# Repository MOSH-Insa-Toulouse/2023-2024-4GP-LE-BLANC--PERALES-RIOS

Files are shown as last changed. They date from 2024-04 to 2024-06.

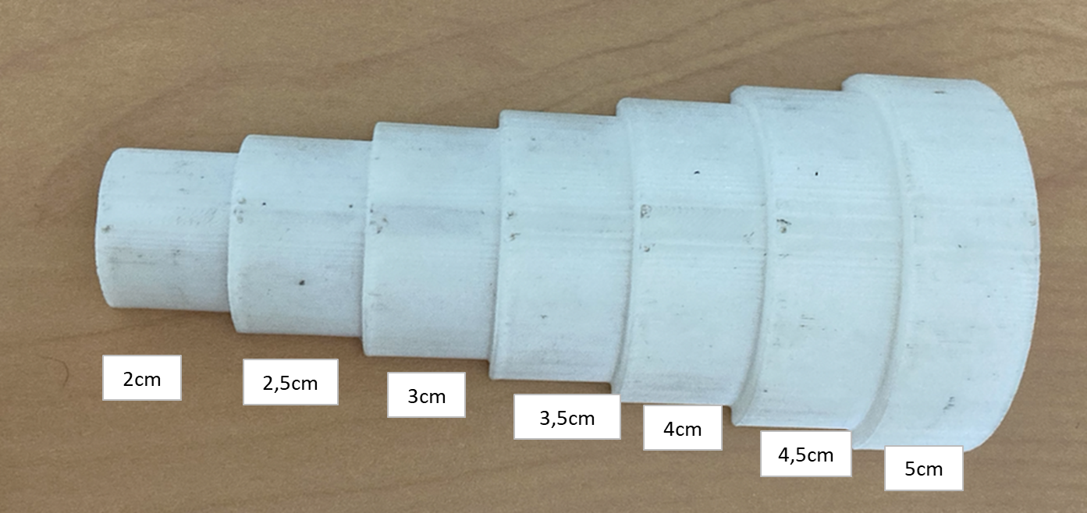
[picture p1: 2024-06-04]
Images/Bench_test.png

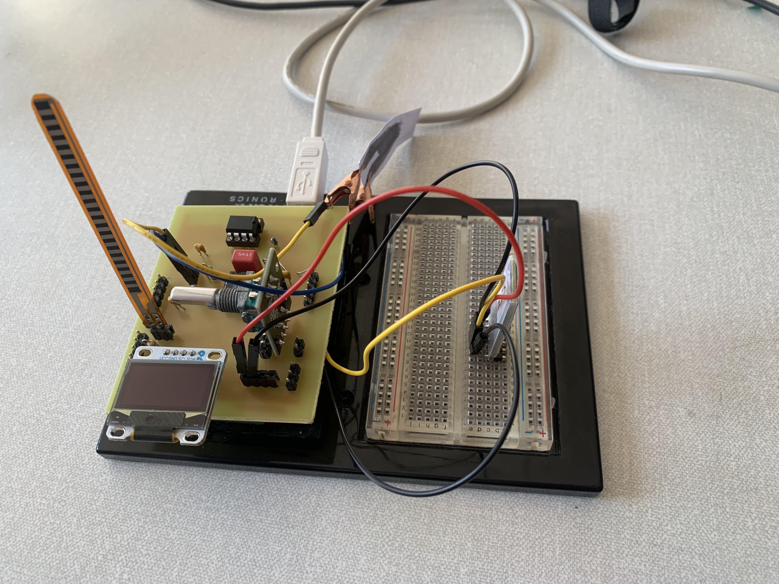
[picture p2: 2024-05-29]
Images/Complete_PCB.jpg

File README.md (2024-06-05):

# Graphite-based sensor project

## Students: Maël LE BLANC, Daniel PERALES RIOS

Département de Génie Physique

Institut National des Sciences Appliquées de Toulouse

# Introduction
The aim of this project is to study a graphite-based low-tech sensor, based on the publication "Pencil Drawn Strain Gauges and Chemiresistors on Paper" by Cheng-Wei Lin, Zhibo Zhao, Jaemyung Kim & Jiaxing Huang, published on Nature in 2014.

According to this research, graphite particles, deposited by coloring a sensor trace, can act as strain gauges. These strain gauges can then be used to measure resistances of the order of the Giga-ohm (10E9 Ohms), for a much cheaper price than buying a multimeter able to measure this order of resistance.

To study this graphene-based low-tech sensor, we have made an amplifier circuit that allows to measure the current flowing through the graphite sensor. This current is very small, and to measure it we would need a very expensive multimeter. Moreover, as the resistance of the graphene sensor depends on each graphite sensor, we have added a digital potentiometer in one of the resistances of the amplifier circuit. This allows for tuning the circuit to each sensor. We have also added a flex sensor to the project. The resistance of this sensor depends on the bending angle applied to it.

All the sensors and measurements are managed through an Arduino UNO board. In this Arduino UNO board, we have also connected an OLED screen that displays the data being measured. We have also implemented a simple menu in the screen that can be controlled through a rotary encoder. All the gathered data is then sent via a Bluetooth® module to an Android device though an app we have built using MIT’s App Inventor.

Finally, we have mounted all the sensors in a PCB we have built from scratch using KiCAD v7.0.

This project covers the entire sensor field, right up to the development of a datasheet and test bench for this sensor.

- [Deliverables](#deliverables)

- [Physics behind the resistance change in the graphite and the flex sensors](#physics-behind-the-resistance-change-in-the-graphite-and-the-flex-sensors)

- [Necessary components and image of the finished project](#necessary-components-and-image-of-the-finished-project)

- [Arduino code](#arduino-code)
  
    - [Potentiometer menu](#potentiometer-menu)
    - [Flex sensor menu](#flex-sensor-menu)
    - [Graphite sensor menu](#graphite-sensor-menu)

- [KiCAD PCB design](#kicad-pcb-design)

    - [Amplifier circuit](#amplifier-circuit)
    - [LTC1050 Operationnal amplifier](#ltc1050-operationnal-amplifier)
    - [MCP41050 Digital potentiometer](#mcp41050-digital-potentiometer)
    - [Graphite sensor](#graphite-sensor)
    - [Flex sensor](#flex-sensor)
    - [KY-040 Rotary encoder](#ky-040-rotary-encoder)
    - [OLED screen](#oled-screen)

- [Android App](#android-app)

- [Test Bench](#test-bench)

# Deliverables

- Arduino shield containing the BT module, the OLED screen...
- Arduino code for controlling the Arduino shield.
- Android app that is able to gather the data sent by the Arduino shield.
- Datasheet describing the results of some measurements for the sensors. 

To write the datasheet, a bench test must be used or built. In our project, we have used a bench test that was already at the department, and that was perfect for our case.

# Physics behind the resistance change in the graphite and the flex sensors

For the graphite and the flex sensors, let’s imagine they were a 2D layer of atoms to which we could apply tension and compression. This 2D layer of atoms would have a mean distance per atom depending on the atomic arrangement. The greater these mean distance between atoms is, the more difficult it is for an electron to “jump” from one atom to another, and vice versa. When these electron “jumps” are coordinated following the same direction (for example when we apply a potential difference between the two extremes of the 2D plane), we can say that an electric current is present. When this happens, it is called "percolation".

On the one hand, when a compression force is applied to that 2D layer of atoms, the atoms would get closer to each other, thus reducing the mean distance per atom, facilitating the flow of an electric current, and reducing then the resistance. 

On the other hand, when a tensile force is applied to the 2D layer of atoms, the atoms would get farther apart from each other, thus increasing the mean distance per atom, making the electron “jumps” less favorable, and increasing the resistance. 

We can see in figure 1 how the compressive and tensile forces affect the geometry of the 2D plane. When generalizing the 2D plane to a 3D thin surface, the principle of the measurement stays the same.

Imagen1

Figure 1: Principle of the resistance measurement for the graphite and flex sensors. Extracted from “Pencil Drawn Strain Gauges and Chemiresistors on Paper”, by Cheng-Wei et al.

# Necessary components and image of the finished project

In figure 2, the finished project, with all the components mounted on the shield, is showed. The only component that not mounted in the shield has been the Bluetooth module, since what we thought to be a connection error was blocking the Arduino code from running.

To carry out this project, we needed: 
  - 1 graphite-based paper sensor
  - 1 flex sensor
  - 1 LTC1050 operational amplifier
  - 1 MCP41050 digital potentiometer
  - 1 KY-040 rotary encoder
  - 1 Arduino UNO
  - 1 OLED screen
  - 1 HC-05 Bluetooth® module
  - Resistances
  - Capacitors

PCB_complet

Figure 2: Image of the complete project. The Bluetooth module is mounted on a separate Arduino breadboard, but this does not have any impact on the functioning of the program.

# Arduino code

The logic behind the Arduino program can be found in the logic chart in figure 3.

bP9DRXin34RtEWMHLN85UvFunudH6WtgvW2CXl2ebIX1efAwHUzUIPunCi1iiZ3WaSZtFWgyJu9HihDAZ5Y2v-X_ae3689IZKkrQgSMH98UbMkpPY45h_X1exu9dOac0t44md4h1WmZg7eYrxoY2OQ4OSv1fxxUlsqthIXJBKMMvp4QZ6CzBfTvxOmbk7He-4ESxC0bkpvJk5C1YOr (1)

Figure 3: Logic chart for the Arduino code, that shows what are the main procedures and methods and what the code mainly does.

The is a main menu with three options, and the user can choose between each of these three options: the potentiometer, the flex sensor and the graphite sensor. These menus are showed below.

## Potentiometer menu

In this menu, the user selects the resistance value to be given to the potentiometer by placing the cursor over the available values. The user exits the calibration menu by pressing the encoder button. 



Figure 4: Potentiometer menu.

## Flex sensor menu

In this menu, the value of the resistance and the value of the angle of the flex sensor are displayed.  



Figure 5: Flex sensor menu.

## Grpahite sensor menu

In this menu, the user can see the current value of the graphite sensor. The user exits to the main menu by pressing the encoder button.



Figure 6: Graphite sensor menu.

# KiCAD PCB design

To realise our PCB, we have used KiCAD under its 7.0 version.

First of all, we had to reproduce the electrical amplifier circuit (resistances, capacitors...) with a few changes and component additions. In order to adjust the gain of our circuit, we have replaced the resistance R2 by an MCP41050 digital potentiometer which can be controlled using the KY-040 rotary encoder. Then, for the realisation of the test bench, we had to add some components that need to be connected to the power source, such as the flex sensor, the Bluetooth® module or the OLED screen. For that, we have created some symbols associated to the new elements. 

On figure 7, it is possible to see our complete electrical circuit realised in KiCAD with the different symbols of the components. 

Sin título (1)

Figure 7 : Complete schematic of the electrical circuit in KiCAD for the project.

Then, the second part is to realise the footprint of the PCB on KiCAD. However, all the components and the whole circuit have to fit on Arduino Uno Shield. So, the spatial arrangement must be thoughtful, while considering the 3D shape of the components and the specifications we have to follow for the PCB printing. 

For the most commons components, we've used some predefined footprints but for the others we've created some specifical footprints thanks to the software. All the footprints can be found in the KiCAD folder.

## Amplifier circuit

The main role of the amplifier is to amplify sensor output voltages to make them measurable.

On figure 8 can be seen the electrical circuit of the amplifier.



Figure 8: Schematic of the operationnal amplifier circuit in KiCAD.

## LTC1050 Operationnal amplifier

The LTC1050 is the operationnal amplifier used in our amplifier circuit that can be observed in figure 9.

DIP-8

Figure 9: LTC1050 operational amplifier.

## MCP41050 Digital potentiometer

The MCP41050 is the digital potentiometer used in our project. It varies up to 50,000 ohms depending on the command sent.
It has eight connections pins as can be seen in figure 10. 

Microchip-MCP41050-I_SN-image

Figure 10: MCP41050 digital potentiometer.

## Graphite sensor

The graphite sensor used in our project is made from paper with a trace to be colored in with different pencils. 
In our electrical circuit, the sensor is connected between the 5V (Vcc) source and the positive input of the amplifier (Vout), as can be seen in figure 11.

Graphite_sensor

Figure 11: Schematic for the graphite sensor. Extracted from Niels Brun and Paul Besnard's GitHub site.

## Flex sensor

The flex sensor, used for comparing the graphite-sensor measures, is mounted in a voltage divider bridge. 

Flex_sensor

Figure 12: Flex sensor. 

## KY-040 Rotary encoder

The rotary encoder is a main part of our project. It allows the user to change the selected menu, enter and exit menus by turning or pressing the encoder.
The rotary encoder has five pins connected to differents parts of the shield, as you can see on figure 13.  

Encodeur_rotatoire

Figure 13: Rotary encoder KY-040.

## OLED screen

On the Arduino shield, the OLED screen is connected to four pins, as you can see on figure 14.

OLED_screen

Figure 14: The OLED screen, with four pins.

# Android app

The Android app has been coded using MIT's app inventor. In figure 15 can be seen a logic chart for the functioning of the app.

Android_app_logic_chart

Figure 15: Logic chart for the Android app.

In figure 16 can be seen the code blocks for the Android app. 

Code_blocks_app (1)

Code_blocks_app (2)

Figure 16: Code blocks for the Android app. 

Moreover, we have coded an improved version of the program with a login function, whose code appears in figure 17.

Code_blocks_app_with_login (1)

Code_blocks_app_with_login (2)

Figure 17: Code blocks for the Android app with the login function.

Next, in figures 18 and 19 are presented the data capture screen and the login screen, respectively.

App_screen

Figure 18: Data capture screen.

App_screen_with_login

Figure 19: Login screen.

# Test bench

The last part of our project was to realize the test bench to acquire the data from our sensors. 

To realize the measures, we have decided to use a test bench consisting of semi-cylinders going from 2 to 5 cm in diameter, with steps of 0.5 cm in between each semi-cylinder, as you can see on figure 20.

Bench_test

Figure 20: Test bench used.

We have tested 5 graphite-sensors. Each, made with a different type of pencil: 3B, 2B, B, H, 2H. 
To carry out the measurements, we placed the sensors on the various cylinders, in tension and compression, as can be seen respectively in figures 21 and 22. This enabled us to measure differences in resistance as a function of pencil type and deformation. 

Deformation_tension

Figure 21: Deformation in tension.

Deformation_compression

Figure 22: Deformation in compression.

In figure 23 the results for the flex sensor in tension are showed. 

Deformation_tension_flex

Figure 23: Results for the flex sensor, in tension.

The complete results are described and presented in the graphite sensors' datasheet, available in the Datasheet folder.

With our results it is found that the softer the pencil is (in our case, 3B is the softer pencil), the less sensitive it is. This is the same conclusion, saving the distance, of Wei et al. in “Pencil Drawn Strain Gauges and Chemiresistors on Paper”.

For any question concerning our sensor project, please contact: perales@insa-toulouse.fr / m_leblan@insa-toulouse.fr

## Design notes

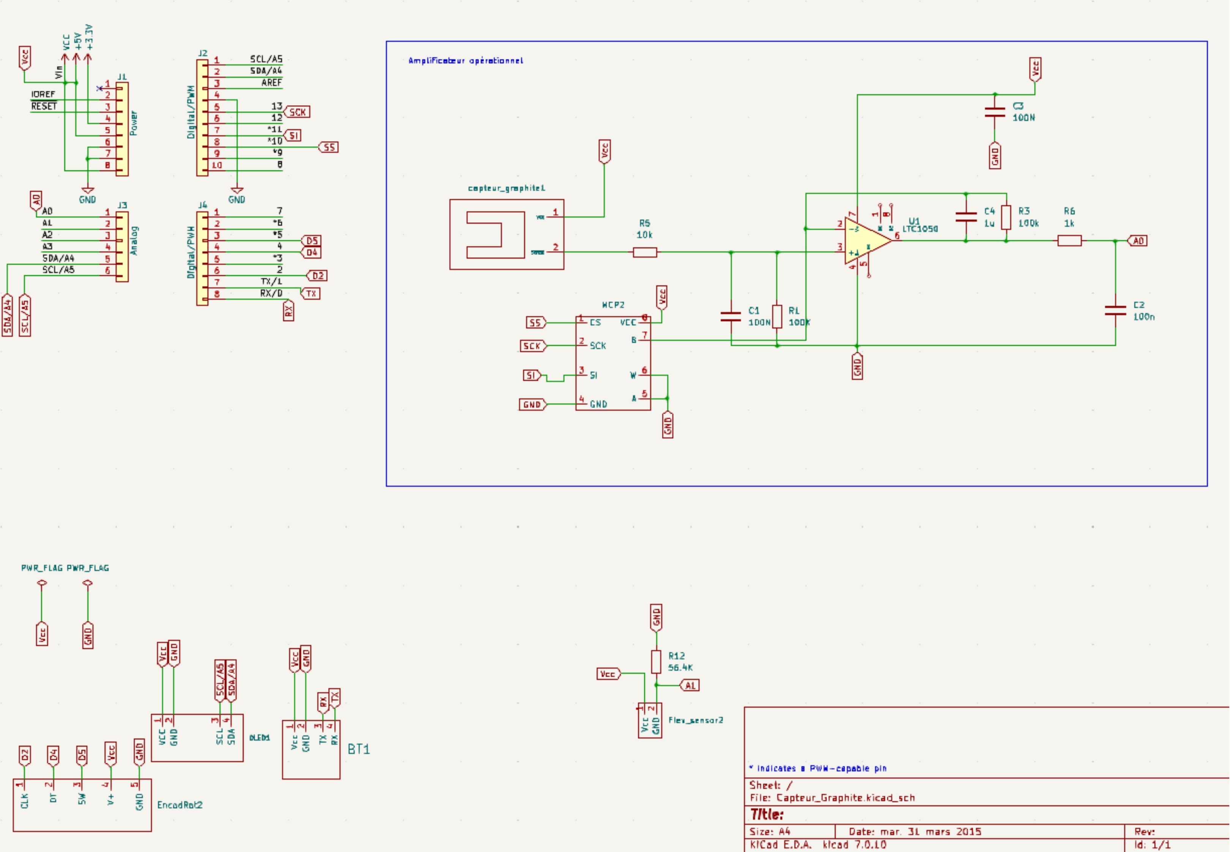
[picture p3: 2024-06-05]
KiCAD_PCB/Complete_schematic_analog.png

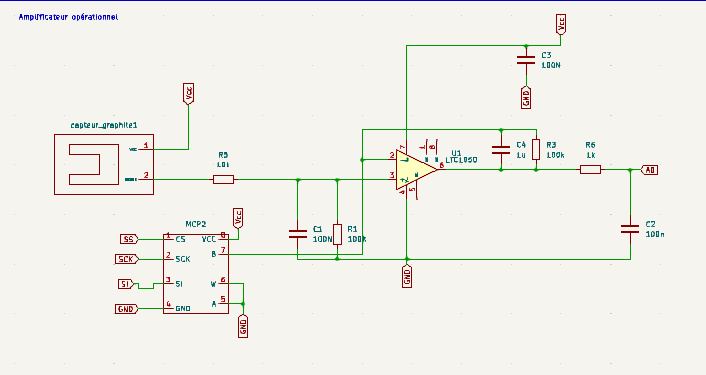
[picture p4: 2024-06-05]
KiCAD_PCB/Amplifier_schematic_analog.png

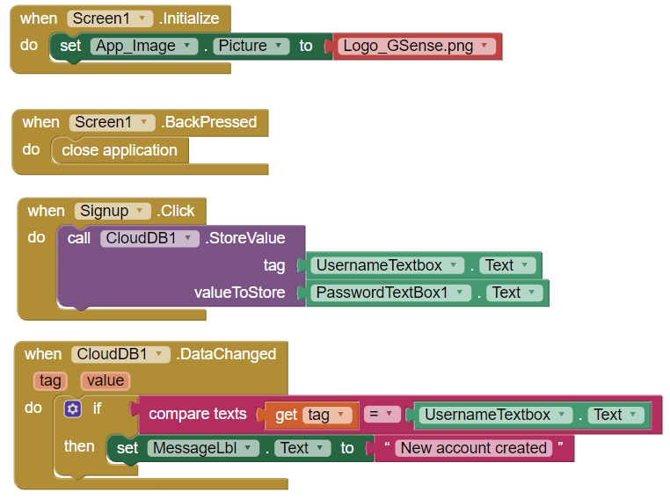
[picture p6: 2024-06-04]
Images/Code_blocks_app_with_login (1).png

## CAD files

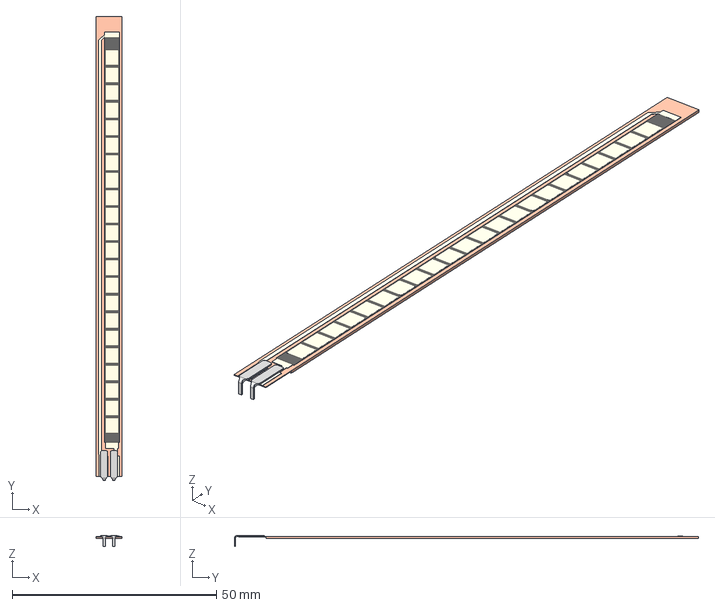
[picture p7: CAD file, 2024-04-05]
KiCAD_PCB/3D_models/flex_sensor/FS-L-0095-103-ST - Assembly.stp
6.45 x 113.5 x 2.77 mm
FS-L-0095-103-ST - Base
FS-L-0095-103-ST - Top

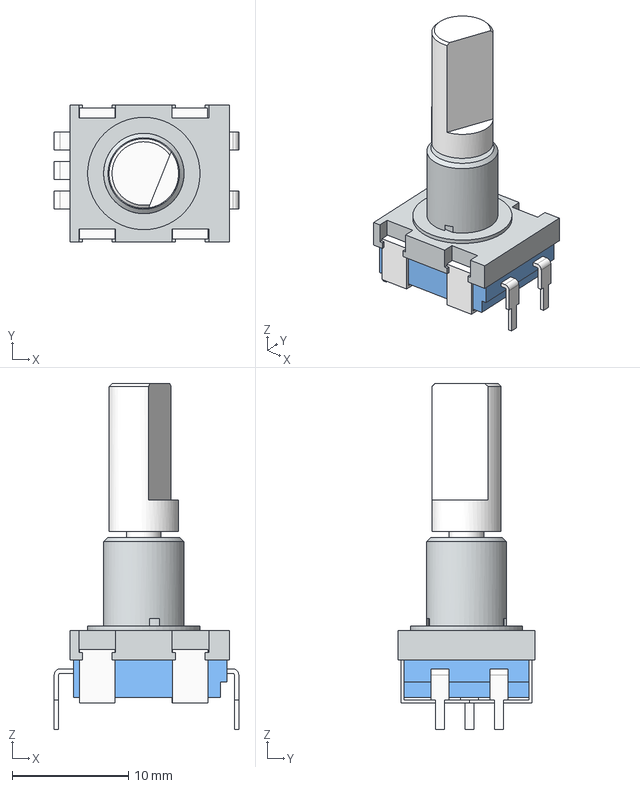
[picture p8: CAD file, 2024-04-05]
KiCAD_PCB/3D_models/rotary encoder step files/Step Files/Rotary Encoder without pcb Assembly.stp
15.8 x 11.8 x 29.7 mm
mtg flange
body_encoder
pins_encoder body_2 x 5
shaft_encoder

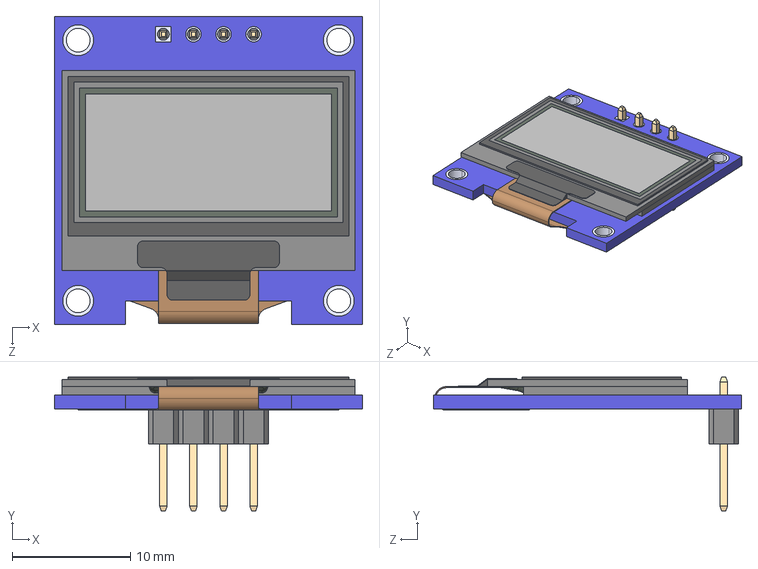
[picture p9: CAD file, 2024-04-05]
KiCAD_PCB/3D_models/DM-OLED096-636--3DModel-STEP-56544.STEP
26.0 x 11.3 x 26.0 mm
DM-OLED096-636_Module
DM-OLED096-636_Panel

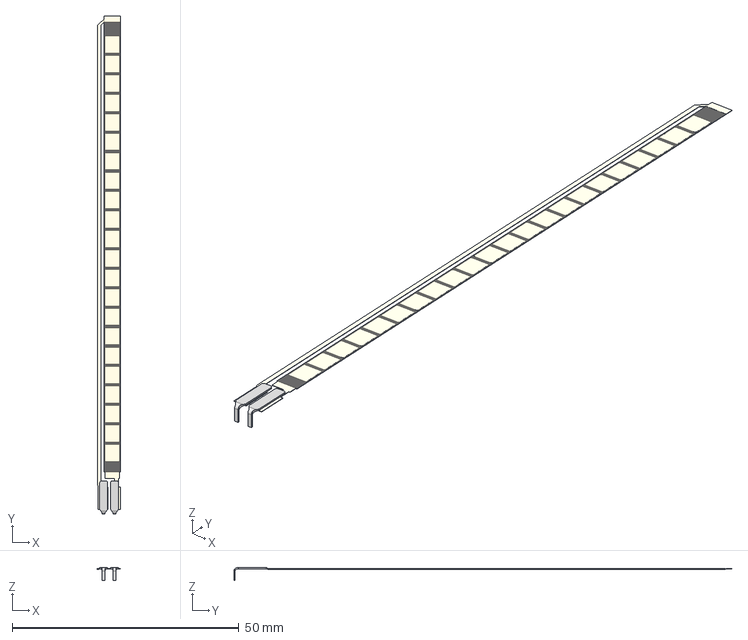
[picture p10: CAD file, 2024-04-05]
KiCAD_PCB/3D_models/flex_sensor/SolidEdge/FS-L-0095-103-ST - Top - Right.stp
5.17 x 109.7 x 2.77 mm

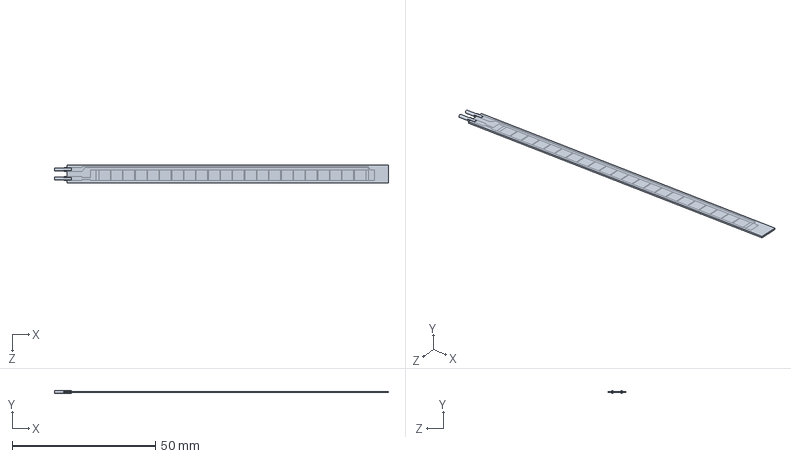
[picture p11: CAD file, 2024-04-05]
KiCAD_PCB/KiCAD/FLEX_SENSOR 115MM/FLEX_SENSOR 115MM.SLDPRT
116.7 x 1.00 x 6.35 mm

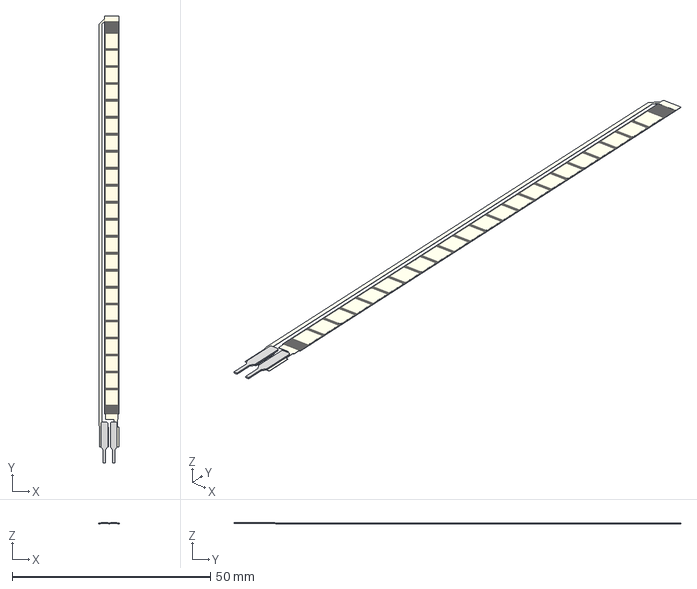
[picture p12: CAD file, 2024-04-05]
KiCAD_PCB/3D_models/flex_sensor/SolidEdge/FS-L-0095-103-ST - Top.stp
5.17 x 112.8 x 0.292 mm

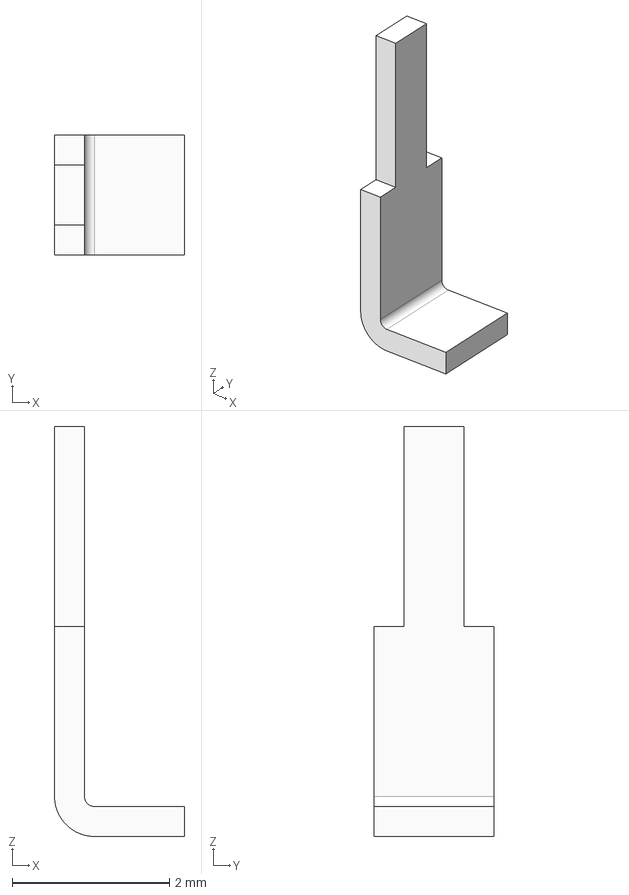
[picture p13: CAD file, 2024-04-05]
KiCAD_PCB/3D_models/rotary encoder step files/Step Files/pins_encoder body_2.stp
1.65 x 1.52 x 5.21 mm

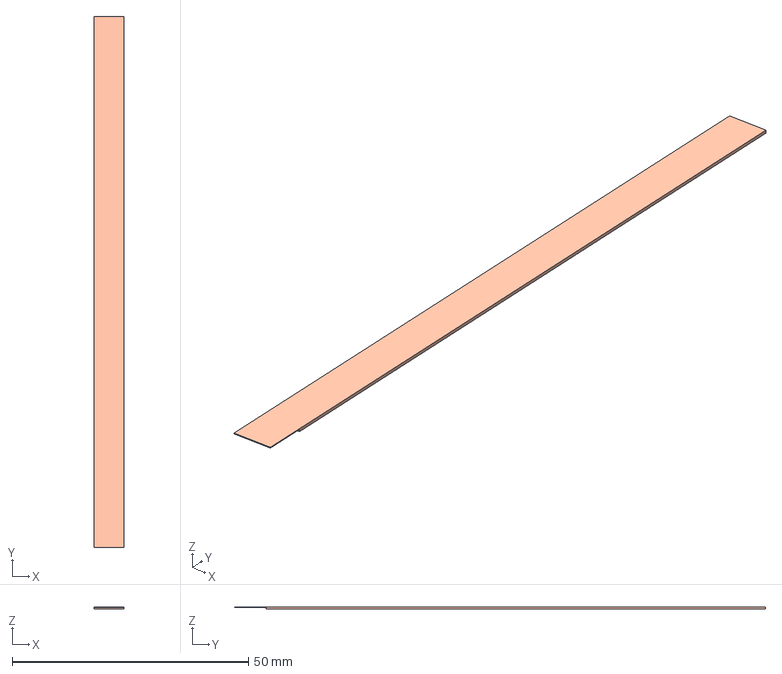
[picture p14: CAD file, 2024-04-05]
KiCAD_PCB/3D_models/flex_sensor/SolidEdge/FS-L-0095-103-ST - Base.stp
6.45 x 112.4 x 0.483 mm

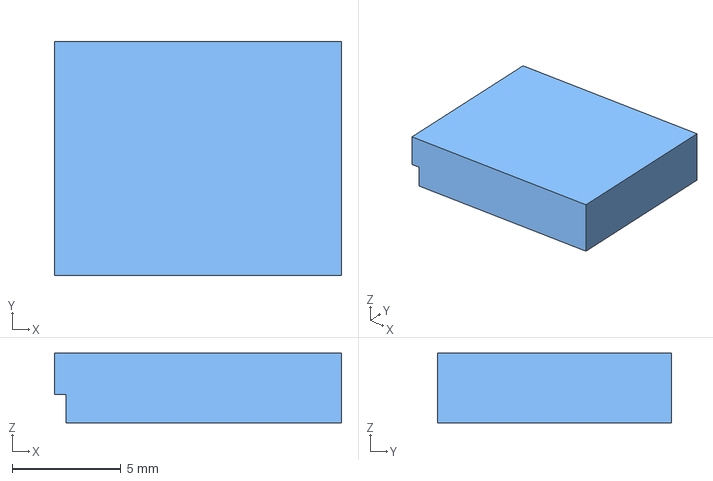
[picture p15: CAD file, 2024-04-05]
KiCAD_PCB/3D_models/rotary encoder step files/Step Files/body_encoder.stp
13.2 x 10.8 x 3.20 mm

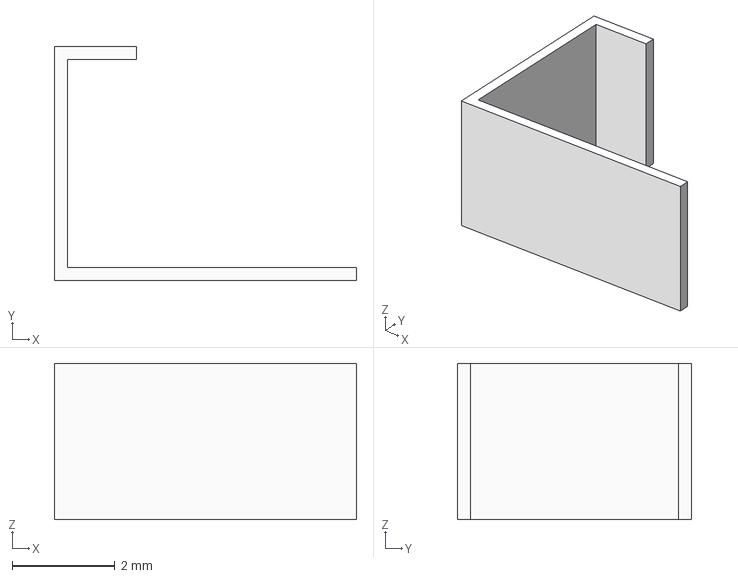
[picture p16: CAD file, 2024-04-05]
KiCAD_PCB/3D_models/rotary encoder step files/Step Files/body_2.stp
5.89 x 4.57 x 3.05 mm

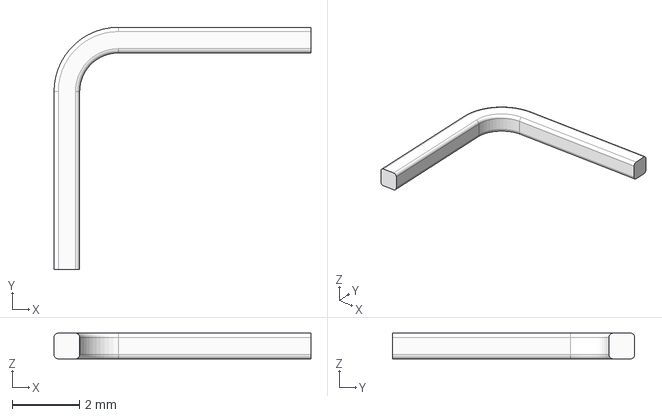
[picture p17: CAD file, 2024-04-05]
KiCAD_PCB/3D_models/rotary encoder step files/Step Files/90d pin_header.stp
7.62 x 7.19 x 0.762 mm

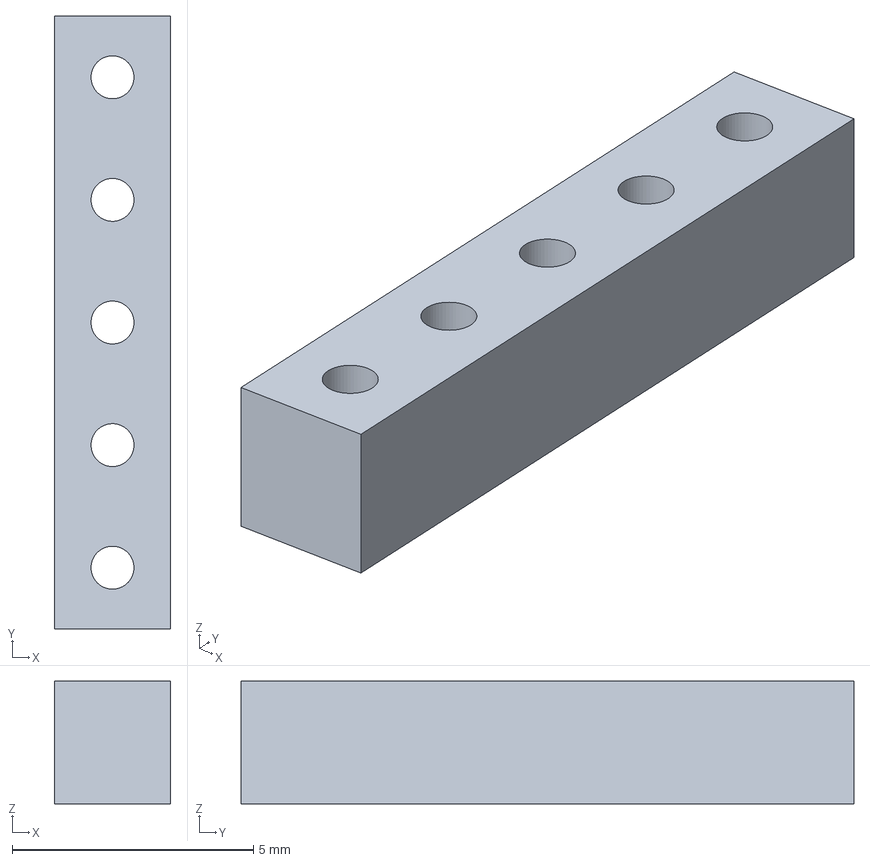
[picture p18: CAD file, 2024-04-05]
KiCAD_PCB/3D_models/rotary encoder step files/Step Files/5 pin header.stp
2.41 x 12.7 x 2.54 mm

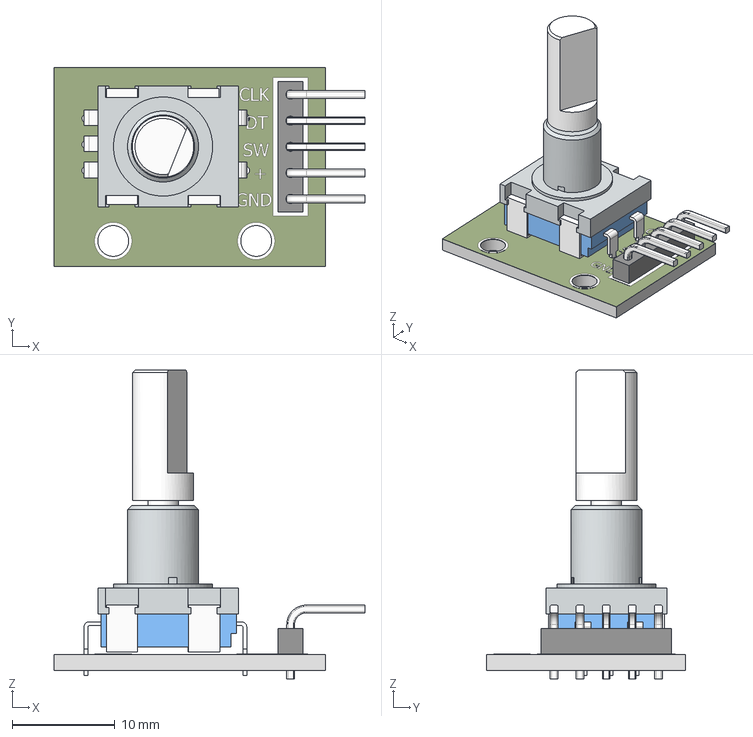
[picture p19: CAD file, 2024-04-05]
KiCAD_PCB/3D_models/rotary encoder step files/Step Files/rotary encoder_chesr_2013.stp
30.3 x 19.3 x 30.1 mm

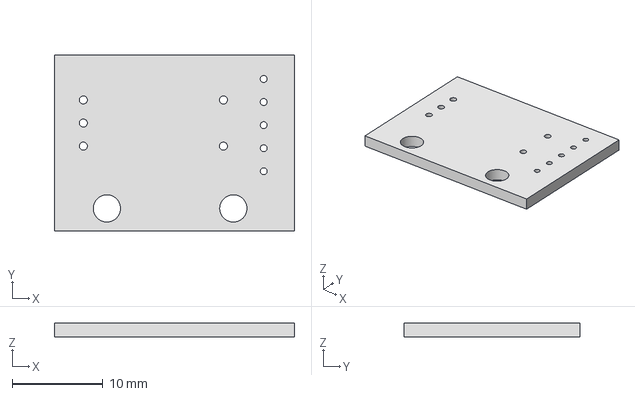
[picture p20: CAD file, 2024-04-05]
KiCAD_PCB/3D_models/rotary encoder step files/Step Files/pcb.stp
26.4 x 19.3 x 1.52 mm

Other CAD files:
KiCAD_PCB/3D_models/rotary encoder step files/Step Files/decal_encoder.stp
KiCAD_PCB/3D_models/rotary encoder step files/Step Files/mtg flange.stp
KiCAD_PCB/3D_models/MCP41050-I_P.STEP

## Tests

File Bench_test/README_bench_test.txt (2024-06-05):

This folder contains the .xlsx file containing the measurements under tension 
and compression for different types of pencil. Some of the measurements had 
to be redone because they appeared to be random, and also some of them were 
extremely high, thus this Excel file could contain errors or not show the actual 
resistance trend for the different types of pencil.

For measuring the values in this .xlsx file, we used a separate amplifier circuit 
as the one from our PCB seemed to have a malfunction and yielded abnormal values. 
Nonetheless, the circuit should be exactly the same as the one in the PCB.

The bench test used for this part was in the GP Department. It consists of seven 
semi-circles with radii from 2 to 5 cm with an increase of 0,5cm in between each semi-circle.

Each type of pencil is analyzed separately in its own sheet and finally the results 
are plotted in the last sheet.

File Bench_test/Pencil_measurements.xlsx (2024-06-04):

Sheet: Mesure_2H
Mesure de la résistance relative avec le crayon 2H
 | Paramètres pour calcul de Rcapteur
 | R1 | 100000.0 | Vcc | 5
 | R2 | 1200.0 | R5 | 10000
 | R3 | 100000
 | Dimensions du capteur (cm) |  | A | 4 | B | 10 | C | 1
 |  |  | D | 24 | E | 2
 | Type de feuille (grammage) |  |  | 160g/m²
 | Expérimentateur coloriage |  |  | Daniel
MESURE EN TENSION
 |  |  | Rayon de courbure (cm) |  |  |  |  |  |  |  | Rayon de courbure (cm)
 |  | Sans rayon | 5 | 4.5 | 4 | 3.5 | 3 | 2.5 | 2 |  | Ro | 5 | 4.5 | 4 | 3.5 | 3 | 2.5 | 2
 | Valeur de Vadc | 3.9 | 3.75 | 3.75 | 4.2 | 4.06 | 3.6 | 3.3 | 2.9 | Rcap | 10701965.81 | 11134444.44 | 11134444.44 | 9929682.54 | 10275878.49 | 11602962.96 | 12667777.78 | 14430229.89
 |  |  |  |  |  |  |  |  |  | ΔR/Ro | 0 | 0.04041113942 | 0.04041113942 | -0.07216274896 | -0.03981393046 | 0.08418987379 | 0.1836869974 | 0.3483718915
MESURE EN COMPRESSION
 |  |  | Rayon de courbure (cm) |  |  |  |  |  |  |  |  | Rayon de courbure (cm)
 |  | Sans rayon | 5 | 4.5 | 4 | 3.5 | 3 | 2.5 | 2 |  | Ro | 5 | 4.5 | 4 | 3.5 | 3 | 2.5 | 2
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

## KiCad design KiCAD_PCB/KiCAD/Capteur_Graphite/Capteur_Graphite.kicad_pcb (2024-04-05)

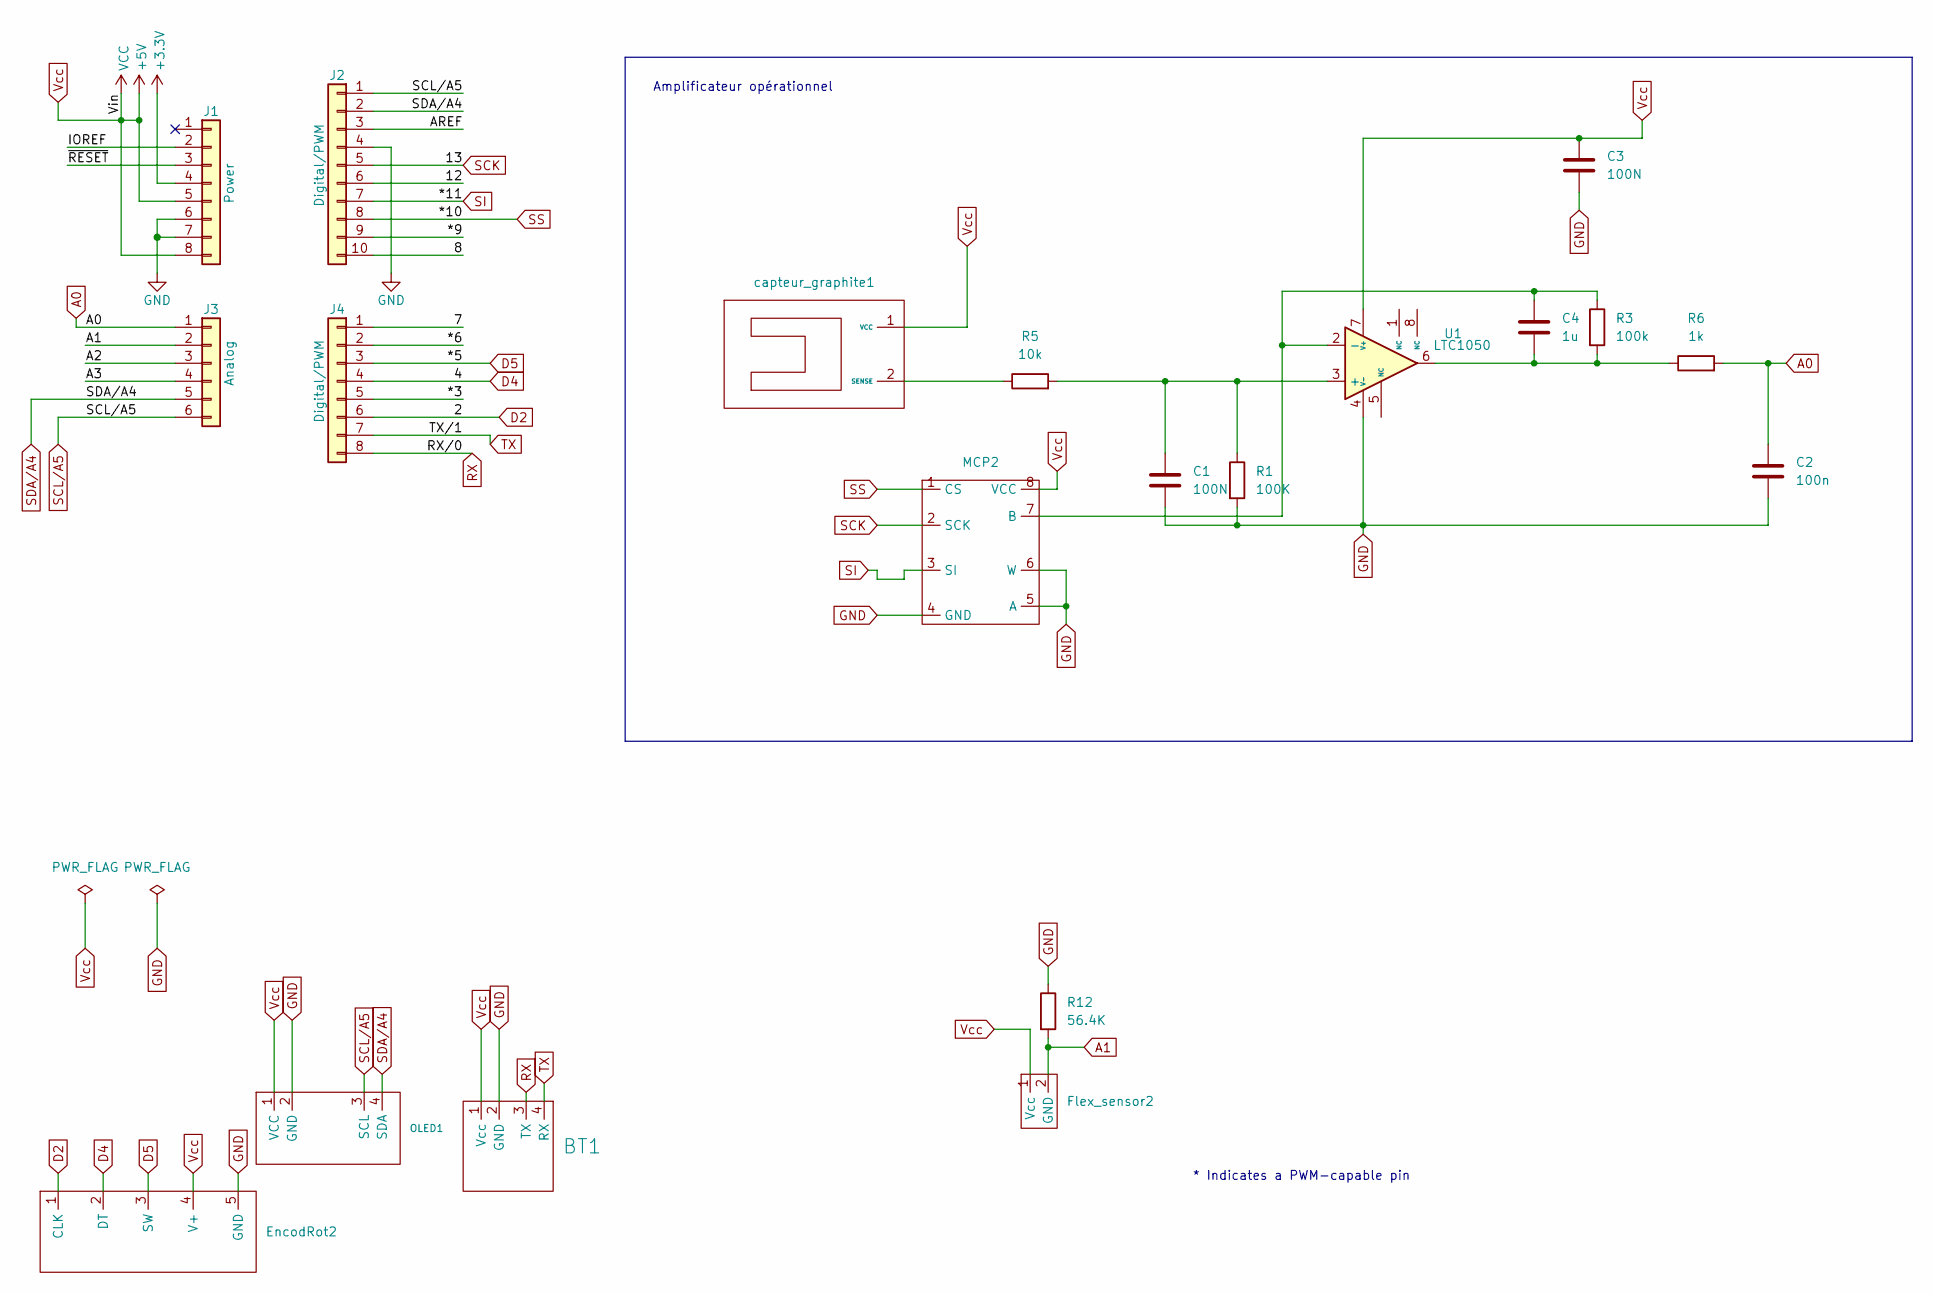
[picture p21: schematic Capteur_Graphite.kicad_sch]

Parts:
BT1: Bluetooth
C1, C3: 100N; C_Radial_D5.0mm_H5.0mm_P2.00mm
C2: 100n; C_Radial_D5.0mm_H5.0mm_P2.00mm
C4: 1u; C_Radial_D5.0mm_H5.0mm_P2.00mm
EncodRot2: Encodeur
Flex_sensor2: FLEX
J1: Power; PinSocket_1x08_P2.54mm_Vertical
J2: Digital/PWM; PinSocket_1x10_P2.54mm_Vertical
J3: Analog; PinSocket_1x06_P2.54mm_Vertical
J4: Digital/PWM; PinSocket_1x08_P2.54mm_Vertical
MCP2: MCP41050
OLED1: OLED
R1: 100K; R_Axial_DIN0204_L3.6mm_D1.6mm_P1.90mm_Vertical
R3: 100k; R_Axial_DIN0204_L3.6mm_D1.6mm_P1.90mm_Vertical
R5: 10k; R_Axial_DIN0204_L3.6mm_D1.6mm_P1.90mm_Vertical
R6: 1k; R_Axial_DIN0204_L3.6mm_D1.6mm_P1.90mm_Vertical
R12: 56.4K; R_Axial_DIN0204_L3.6mm_D1.6mm_P1.90mm_Vertical
U1: LTC1050
capteur_graphite1: Capteur_graphite

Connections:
+3V3: J1.4
/7: J4.1
/8: J2.10
/12: J2.6
/*3: J4.5
/*6: J4.2
/*9: J2.9
/A2: J3.3
/A3: J3.4
/AREF: J2.3
/IOREF: J1.2
/~RESET: J1.3
A0: C2.2, J3.1, R6.2
A1: Flex_sensor2.2 (GND), J3.2, R12.2
D2: EncodRot2.1 (CLK), J4.6
D4: EncodRot2.2 (DT), J4.4
D5: EncodRot2.3 (SW), J4.3
GND: BT1.2 (GND), C1.2, C2.1, C3.2, EncodRot2.5 (GND), J1.6, J1.7, J2.4, MCP2.4 (GND), MCP2.5 (A), MCP2.6 (W), OLED1.2 (GND), R1.2, R12.1, U1.4 (V-)
unnamed: C4.2, R3.2, R6.1, U1.6
unnamed: C4.1, MCP2.7 (B), R3.1, U1.2 (-)
unnamed: C1.1, R1.1, R5.2, U1.3 (+)
unnamed: R5.1, capteur_graphite1.2 (SENSE)
RX: BT1.3 (TX), J4.8
SCK: J2.5, MCP2.2 (SCK)
SCL/A5: J2.1, J3.6, OLED1.3 (SCL)
SDA/A4: J2.2, J3.5, OLED1.4 (SDA)
SI: J2.7, MCP2.3 (SI)
SS: J2.8, MCP2.1 (CS)
TX: BT1.4 (RX), J4.7
Vcc: BT1.1 (Vcc), C3.1, EncodRot2.4 (V+), Flex_sensor2.1 (Vcc), J1.5, J1.8, MCP2.8 (VCC), OLED1.1 (VCC), U1.7 (V+), capteur_graphite1.1 (VCC)

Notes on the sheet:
* Indicates a PWM-capable pin
Amplificateur opérationnel

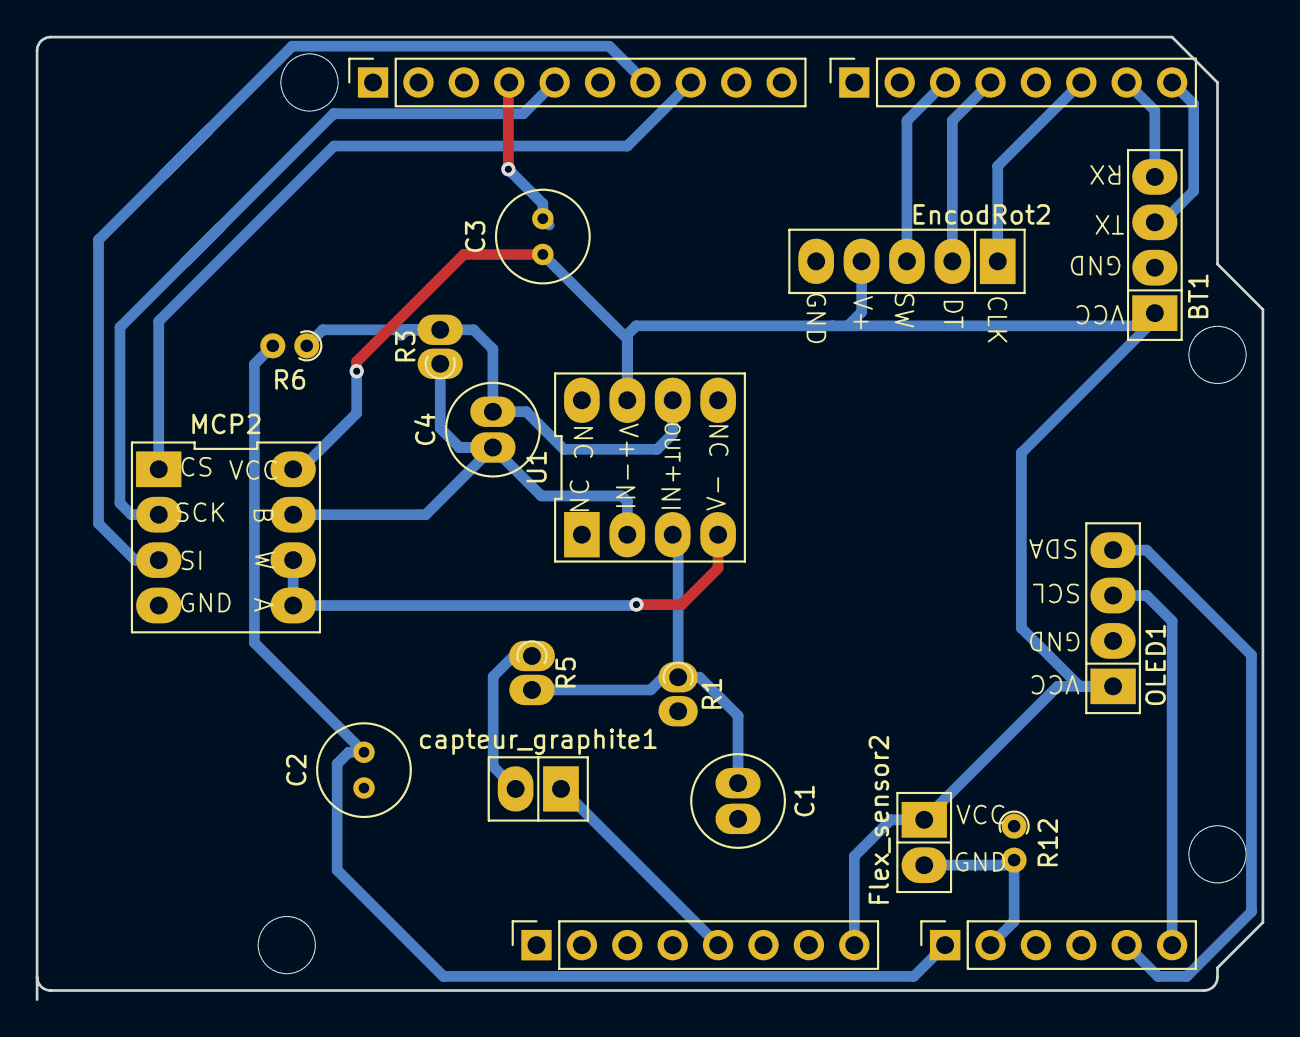
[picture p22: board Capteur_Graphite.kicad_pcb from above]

Board: 2 copper layers, 68.6 x 53.8 mm, 24 parts (0 on the bottom side), 18 nets.

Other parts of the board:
MH1, MH2, MH3, MH4: MountingHole_3.2mm

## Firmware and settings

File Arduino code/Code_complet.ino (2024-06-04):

/*
Complete Arduino code for "Projet capteur".

Students: Maël LE BLANC, Daniel PERALES RIOS

Year / Department: 4th Year / Génie Physique

Description of the project:
    This code reads the values from a flex sensor and a graphite sensor, and allows to adjust the value of a digital potentiometer. This
    data is then displayed on an OLED screen, which is controlled thanks to a rotary encoder that has also a button. This rotary encoder
    allows to choose the items in the menu and to enter the selected item by pressing the switch button in the encoder. All the acquired 
    data is then sent via Bluetooth to an HC-05 Bluetooth module, that then sends this data to a remote device, such a smartphone. To allow
    communication between the Bluetooth module and the smartphone, we have build an app using MIT's App Inventor site and then uploading
    the .aia file to the smartphone via a QR code.
*/

// LIBRARIES
#include <Adafruit_SSD1306.h>
#include <SoftwareSerial.h>
#include <SPI.h>

//--------------------------------------- PARAMETER DEFINITION ---------------------------------------------------

// PINS: defining their values and other parameters
#define encoderPinA 2                   // CLK Output A
#define encoderPinB 4                   // DT Output B
#define Switch 5                        // Switch connection
#define nombreDePixelsEnLargeur 128     // Parameters for the OLED screen
#define nombreDePixelsEnHauteur 64
#define brocheResetOLED -1
#define adresseI2CecranOLED 0x3C
#define MCP_NOP 0b00000000              // Parameters for the digital potentiometer
#define MCP_WRITE 0b00010001
#define MCP_SHTDWN 0b00100001
#define rxPin 9                        // Pin 9 as RX, connecto to TX in the HC-05
#define txPin 8                        // Pin 8 as TX, connecto to RX in the HC-05
#define baudrate 9600                  // Chosen baudrate for the Bluetooth, to avoid bugs

// OLED SCREEN AND BLUETOOTH MODULE: declaring the associated objects
Adafruit_SSD1306 ecranOLED(nombreDePixelsEnLargeur, nombreDePixelsEnHauteur, &Wire, brocheResetOLED);
SoftwareSerial mySerial(rxPin, txPin);
char data_[] = {}; 

// GRPAHITE SENSOR: constants and variables definition
float range = pow(10,-6);               // To have MOhms
float Vadc = 0.0;
float R1 = 100000.0;
float R3 = 100000.0;
float R5 = 10000.0;
float Rc = 0.0;                         // Resistance of the graphite sensor

// FLEX SENSOR: constants and variables definition
const int flexPin = A1;                 // Pin connected to voltage divider output
const float VCC = 5.0;                  // Voltage at Ardunio 5V line
const float R_DIV = 56000.0;            // Resistor used to create a voltage divider
const float flatResistance = 31000.0;   // Resistance when flat
const float bendResistance = 67000.0;   // Resistance at 90 deg bending
float Rflex = 0.0;
float angle = 0.0;

// ROTARY ENCODER AND SWITCH BUTTON: variable definition
int switchState;                        // The current reading from the switch pin
int lastSwitchState = HIGH;             // The previous reading from the switch pin (switch is HIGH when we don't press)
long lastEncoderValue = 0;              // Used for the selection of the menu
long lastPotValue = 0;                  // Used for the digital potentiometer
long lastDebounceTime = 0;              // The last time the output pin was toggled
long debounceDelay = 40;                // The debounce time, increase if the output flickers
bool button_pressed = false;            // This variable becomes true whenever the switch button is pressed, false otherwise
volatile long encoderValue = 0;         // This variable will store the value of the rotary encoder for moving through the menus
volatile long encoder_for_pot = 0;      // This variable will store the value of the rotary encoder for selecting the potentiometer resistance

// MENU DISPLAY: constants and variables definition
bool mainMenu = true;                                                   // This bool is true when we are in the main menu, false otherwise. Useful to avoid bugs
const char* menuItems[] = {"Potentiometer", "Flex Sensor",
                           "Graphite Sensor"};                          // Definition of menu items. We avoid using String, as they are memory-intensive, and we use a more C-style constant.
const char* potentiometerItems[] = {"DigiPot (50k) setting",
                                    "Value R2:", "", "BACK"};           // Definition of items in the potentiometer screen
const char* flexItems[] = {"Flex sensor reading", "Resistance value:",
                            "", "Bend angle:", "", "BACK"};             // Definition of items in the flex sensor screen
int selectMenu = 0;                                                     // Menu items are defined from 0 to x (depending on the menu)


// DIGITAL POTENTIOMETER: constants and variables definition
const int ssMCPin = 10;                               // Define the slave select for the digital potentiometer
float rWiper = 125.0;
float max_value_pot = 50000.0;                        // Maximum resistance for the digital potentiometer (we supposed here 100k)
int valuePot = 100;                                   // valeur initiale envoyée au potentiomètre
float R2 = (float(valuePot)/256.0)*max_value_pot;     // We set up the value of the digital potentiometer at a default value

//----------------------------------------------------------------------------------------------------------------


void setup() {
    // ROTARY ENCODER AND SWITCH BUTTON
    pinMode(encoderPinA, INPUT);        // Use internal pull-up resistors for the encoder
    digitalWrite(encoderPinA, HIGH);    // Turn on pull-up resistor
    pinMode(encoderPinB, INPUT);
    digitalWrite(encoderPinB, HIGH);    // Turn on pull-up resistor
    pinMode(Switch, INPUT);
    digitalWrite(Switch, HIGH);         // Turn on pull-up resistor

    // DIGITAL POTENTIOMETER
    pinMode(ssMCPin, OUTPUT);
    digitalWrite(ssMCPin, HIGH);        // SPI chip disabled
    SPI.begin();

    // FLEX SENSOR
    pinMode(flexPin, INPUT);

    // BLUETOOTH MODULE
    pinMode(rxPin, INPUT);
    pinMode(txPin, OUTPUT);
    mySerial.begin(baudrate);

    // INTERRUPTION FOR THE ROTARY ENCODER
    attachInterrupt(0, updateEncoder, CHANGE);

    // OLED SCREEN SETUP
    if (!ecranOLED.begin(SSD1306_SWITCHCAPVCC, adresseI2CecranOLED))
        while (1); // If the screen doesn't start, the program stays blocked here forever
    ecranOLED.clearDisplay();
    ecranOLED.setTextColor(SSD1306_WHITE);

    // SERIAL COMMUNICATION INITIALIZATION
    //Serial.begin(baudrate);
}


void loop() {
    if (mainMenu) {
        displayMenu();
        updateSelectedItem(encoderValue, (sizeof(menuItems) / sizeof(menuItems[0])));
        switchButton();
    }
    else {
        handleMenuItemSelection(selectMenu);
        switchButton();
    }
    delay(100);                                             // We add a delay between loops for stability, while still having a responsive display
}


void displayMenu() {
  ecranOLED.clearDisplay();
  for (int i = 0; i < sizeof(menuItems) / sizeof(menuItems[0]); i++) {
    if (i == selectMenu) {
      ecranOLED.setTextColor(SSD1306_BLACK, SSD1306_WHITE); // Highlight selected item
    } else {
      ecranOLED.setTextColor(SSD1306_WHITE);                // Regular color for other items
    }
    ecranOLED.setCursor(0, i * 10);                         // Adjust position for each item
    ecranOLED.print(menuItems[i]);                          // Print each element
  }
  ecranOLED.display();                                      // Display all the elements from the buffer
}


void handleMenuItemSelection(int selectMenu) {
  switch (selectMenu) {       // For each case, if the switch button was pressed, we enter each menu respectively
    case 0:                   // Potentiometer setting using a dedicated function
      displayPotentiometer(valuePot);
      break;
    case 1:                   // Flex sensor reading and display using a dedicated function
      displayFlexSensor();
      break;
    case 2:                   // Graphite sensor reading and display using a dedicated function
      displayGraphiteSensor();
      break;
    default:                  // In case a bug occurs with selectMenu, the code breaks here to avoid extra bugs
      break;
  }
}


void graphiteMeasure() {
    /*
    Calculation of the graphite sensor's resistance.
    */

    float V = analogRead(A0);
    Serial.println("V: " + String(V));
    Vadc = V*5.0/1024.0;           // Voltage value of the sensor
    Serial.println("Vadc: " + String(Vadc));
    Rc = ((R1*(1+R3/R2)*(VCC/Vadc))-R1-R5)*range;     // Conversion to resistance
}


void flexMeasure() {
   /*
   Calculation of the flex sensor's resistance.
   */

   int ADCflex = analogRead(flexPin);                               // Read the ADC, and calculate voltage and resistance from it
   float Vflex = (ADCflex / 1024.0) * VCC;
   Rflex = R_DIV * (VCC / Vflex - 1.0);                             // We calculate the approximate resistance value
   angle = map(Rflex, flatResistance, bendResistance, 0, 90.0);     // Use the calculated resistance to estimate the sensor's bend angle
}


void updateEncoder() {
    /*
    This function allows to control the menu when the rotary encoder is turned. This function takes as input the
    number of elements of each menu to modify the last element than can be selected accordingly.
    */

    if (mainMenu){
      if (digitalRead(encoderPinB) == HIGH) {
          encoderValue++;
      }
      else {
          encoderValue--;
      }
    }
    else if (selectMenu == 0) {
      if (digitalRead(encoderPinB) == HIGH) {
          encoder_for_pot++;
      }
      else {
          encoder_for_pot--;
      }
    }

}

void updatePotentiometerValue(){
  if (encoder_for_pot != lastPotValue) {  // If we turn the encoder, then the selectedItem variable is increased
      valuePot = valuePot + 10;           // valuePot goes from 0 to 255. 255 corresponds to 50 kohms
      if (valuePot > 255){
        valuePot=0;                       // If valuePot is bigger than 255, we reset its value to 0
      }
  }
  lastPotValue = encoder_for_pot;         // The last value from the encoder is updated
  valuePot = constrain(valuePot, 0, 255);
}


void updateSelectedItem(int encoderValue, int NumberOfItems) {
  encoderValue = abs(encoderValue % NumberOfItems);
  if (encoderValue != lastEncoderValue) {     // If we turn the encoder, then the selectedItem variable is increased
      selectMenu++;
      if (selectMenu == NumberOfItems) {
          selectMenu = 0;                     // If we reach the last element from the menu, the selectedItem is reset to the first element
      }
  }
  lastEncoderValue = encoderValue;            // The last value from the encoder is updated
}


void SPIWrite(uint8_t cmd, uint8_t res, uint8_t ssPin) {
  /*
  This function controls the communication between the Arduino and the digital potentiometer
  */

  // https://www.arduino.cc/en/Reference/SPISettings
  updatePotentiometerValue();
  R2 = ((max_value_pot * res) / 256 ) + rWiper;
  SPI.beginTransaction(SPISettings(14000000, MSBFIRST, SPI_MODE0));
  digitalWrite(ssPin, LOW);   // SS pin low to select chip
  SPI.transfer(cmd);          // Send command code
  SPI.transfer(res);          // Send associated value
  digitalWrite(ssPin, HIGH);  // SS pin high to de-select chip
  SPI.endTransaction();
}


void switchButton() {
  /*
  This function controls the reading of the switch button. It has debouncing logic to minimize bad readings.
  */

  // Check if the switch button is pressed and enough time has passed since the last press
  if (digitalRead(Switch) == LOW && (millis() - lastDebounceTime) >= debounceDelay) {
    // Record the time when the button was pressed
    lastDebounceTime = millis();

    // Set the button_pressed flag only if it's not already set
    if (!button_pressed) {
      button_pressed = true;

      // If we were in the main menu, switch to the menu item view
      if (mainMenu) {
        mainMenu = false;
      } else {
        // If we were in a menu item view, switch back to the main menu
        mainMenu = true;         
      }
    }
  } else {
    // Reset button_pressed if the button is released
    button_pressed = false;
  }
}


void sendBluetooth(float data) {
  /*
  This function sends all the gathered data to the Bluetooth module, that transfers the data to a mobile phone through an Android app.
  To separate the different data, we will use a pipe character ("|").
  */
  
  dtostrf(data,6, 2, data_);
  mySerial.println(data_ );                   // Sending the data through Bluetooth
  delay(50);                                  // Introducing a small delay for data transfer + stability
}


void displayPotentiometer(int valuePot) {
    /*
    Dedicated funciton for the menu corresponding to the digital potentiometer and its setting.
    */

    ecranOLED.clearDisplay();
    SPIWrite(MCP_WRITE, valuePot, ssMCPin);
    dtostrf(R2, 6, 2, potentiometerItems[2]);         // Update the value of the potentiometer resistance, which is set at the beginning at a default value
    for (int i = 0; i < sizeof(potentiometerItems) / sizeof(potentiometerItems[0]); i++) {
        ecranOLED.setTextColor(SSD1306_WHITE);        // Regular color for other items
        ecranOLED.setCursor(0, i * 10);               // Adjust position for each item
        ecranOLED.print(potentiometerItems[i]);       // Print each element
    }
    switchButton();
    ecranOLED.display();
}


void displayFlexSensor() {
    ecranOLED.clearDisplay();
    flexMeasure();
    dtostrf(Rflex, 6, 2, flexItems[2]);         // Update the values of the resistance and the angle of the flex sensor
    dtostrf(angle, 6, 2, flexItems[4]);
    for (int i = 0; i < sizeof(flexItems) / sizeof(flexItems[0]); i++) {
        ecranOLED.setTextColor(SSD1306_WHITE);  // Regular color for other items
        ecranOLED.setCursor(0, i * 10);         // Adjust position for each item
        ecranOLED.print(flexItems[i]);          // Print each element
    }
    switchButton();
    sendBluetooth(Rflex); 
    ecranOLED.display();
}


void displayGraphiteSensor() {
    ecranOLED.clearDisplay();
    graphiteMeasure();
    ecranOLED.setTextColor(SSD1306_WHITE);
    ecranOLED.setCursor(0, 0);
    ecranOLED.print(Rc);
    sendBluetooth(Rc);
    switchButton();     
    ecranOLED.display();
}

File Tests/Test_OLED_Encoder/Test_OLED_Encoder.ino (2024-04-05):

#include <Adafruit_SSD1306.h>

// Parameter definition
/////////////////////////////////////////////////////////////////////////
#define encoderPinA 2 // CLK Output A
#define encoderPinB 4 // DT Output B
#define Switch 5 // Switch connection
#define nombreDePixelsEnLargeur 128 // Parameters for the OLED screen
#define nombreDePixelsEnHauteur 64
#define brocheResetOLED -1
#define adresseI2CecranOLED 0x3C

volatile unsigned int encoderValue = 0;
long lastEncoderValue = 0;

long lastDebounceTime = 0;
long debounceDelay = 120;
bool button_pressed = false; 


Adafruit_SSD1306 ecranOLED(nombreDePixelsEnLargeur, nombreDePixelsEnHauteur, &Wire, brocheResetOLED);

String menuItems[] = {"Potentiometer", "Flex Sensor", "Graphite Sensor"}; // Definition of menu items
int selectedItem = 0; // Menu items are defined from 0 to 2
/////////////////////////////////////////////////////////////////////////

void setup() {
  pinMode(encoderPinA, INPUT); // Use internal pull-up resistors for the encoder
  digitalWrite(encoderPinA, HIGH); // Turn on pullup resistor
  pinMode(encoderPinB, INPUT);
  digitalWrite(encoderPinB, HIGH); // Turn on pullup resistor

  attachInterrupt(0, updateEncoder, RISING); // Whenever the encoderPinB changes state, an interruption occurs.
  //attachInterrupt(digitalPinToInterrupt(Switch), switchButton, RISING); // Whenever the switch button is pressed, an interruption is raised
  if (!ecranOLED.begin(SSD1306_SWITCHCAPVCC, adresseI2CecranOLED))
    while (1); // Program stops (infinite loop) if something goes wrong here
  ecranOLED.clearDisplay();
  ecranOLED.setTextColor(SSD1306_WHITE);
  Serial.begin(9600);
}

void loop() {
  displayMenu();
  //handleMenuItemSelection(selectedItem);
  encoderValue = abs(encoderValue % 3); 
  Serial.println(encoderValue); // To debug
  if (encoderValue != lastEncoderValue) { // If we turn the encoder, then the selectedItem variable is increased
    selectedItem++;
    if (selectedItem == 3) {
      selectedItem = 0; // If we reach the last element from the menu, the selectedItem is reset to the first element
    }
  } 
  lastEncoderValue = encoderValue; // The last value from the encoder is updated
  Serial.println("Selected:" + String(selectedItem)); // To debug
  delay(150); // We add a delay between loops for stability, while still having a responsive display
}

void displayMenu() {
  ecranOLED.clearDisplay();
  for (int i = 0; i < sizeof(menuItems) / sizeof(menuItems[0]); i++) {
    if (i == selectedItem) {
      ecranOLED.setTextColor(SSD1306_BLACK, SSD1306_WHITE); // Highlight selected item
    } else {
      ecranOLED.setTextColor(SSD1306_WHITE); // Regular color for other items
    }
    ecranOLED.setCursor(0, i * 10); // Adjust position for each item
    ecranOLED.print(menuItems[i]); // Print each element
  }
  ecranOLED.display();
}


void handleMenuItemSelection(int selectedItem) {
  // Implement actions for each menu item
  switch (selectedItem) {
    case 1:
      if (button_pressed) { // For each case, if the switch button was pressed, we enter each menu respectively
      
      }
    case 2:
      if (button_pressed) {
        
      }
    case 3:
      if (button_pressed) {
        
      }
    default:
      break;
  }
}

void updateEncoder() {
  if (digitalRead(encoderPinB) == HIGH) {
    encoderValue++;
  }
  else {
    encoderValue--;
  }
}

void switchButton() {
  // Debouncing logic for the switch button
  long currentTime = millis();
  lastDebounceTime = currentTime;
  while (currentTime - lastDebounceTime < debounceDelay) {
    currentTime = millis(); // The function waits for the debounce delay to pass, and then we read the value of the switch again
  }
  if (Switch == HIGH) { // If, after the debounce delay, the Switch is still high, we have effectively pressed the button
    button_pressed = true; // We choose the selected option
  }
}

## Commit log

2024-04-05 Add files via upload
    Uploading all the previous files
    [5 pin header.stp, 90d pin_header.stp, Capteur_Graphite.kicad_pcb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]
2024-04-20 Update README.md
    update PCB
2024-05-29 Delete KiCAD/KiCADv6 directory
    fock
2024-05-29 add kicad file
    kicad
    [Capteur_Graphite.kicad_pcb, Capteur_Graphite.kicad_sch]
2024-05-29 Update README.md
    kicad part in readme without images
2024-06-04 Add files via upload
    Added bench test
    [Pencil_measurements.xlsx]
2024-06-04 Add files via upload
    Added all the KiCAD files and the 3D models
    [5 pin header.stp, 90d pin_header.stp, Capteur_Graphite.kicad_pcb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]
